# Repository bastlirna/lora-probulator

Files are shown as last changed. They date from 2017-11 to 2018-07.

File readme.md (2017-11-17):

# LoRa Probulator

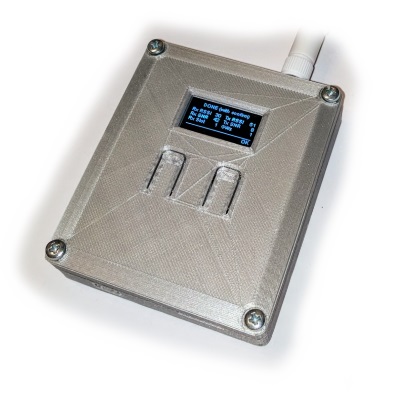
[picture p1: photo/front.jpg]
LoRa Probulator photo


*Yat Another LoRaWAN Tester*

 

<br>

## Motivation

TBD

## Key Features

- Send LoRaWAN message on button press
- Periodic sending
- Configurable message parameters (confirmation, payload, SF, etc.)
- Multiple device (ABP/OTAA, several keys configuration for testing several network providers)  

For more detail about features see [Firmware project](https://github.com/bastlirna/lora-probulator/projects/1) where are list of all ideas, selected requirements and progress of its implementation.

## Build

### Hardware

What do you need:

- [BOM](hw/bom.md)
- [PCB](https://github.com/bastlirna/lora-probulator/blob/master/hw/pcb/lora-tester-top.png)
- [3D printed enclosure ](https://github.com/bastlirna/lora-probulator/blob/master/hw/enclosure/stl/_full_preview.stl) 

For more detail see [schematics](https://github.com/bastlirna/lora-probulator/blob/master/hw/lora-tester.pdf).

### Firmware

FW is written in [Arduino libraries for ESP32](https://github.com/espressif/arduino-esp32) and build with [PlatformIO](http://platformio.org/).

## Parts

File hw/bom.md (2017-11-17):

# BOM

*What do you need:*

- Wemos LOLIN32 (ESP32 board with USB converter and battery charger)
- RFM95 (LoRa radio module)
- I2C OLED display
- 2 buttons and switch
- SMA pcb edge connector + 868 MHz antenna 
- Few resistors and capacitors
- Li-Pol battery (300 mAh)

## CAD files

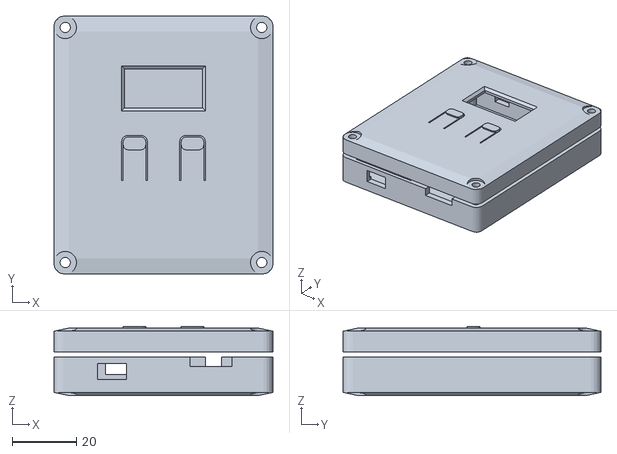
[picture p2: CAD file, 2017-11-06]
hw/enclosure/stl/_full_preview.stl
68.0 x 80.0 x 21.5

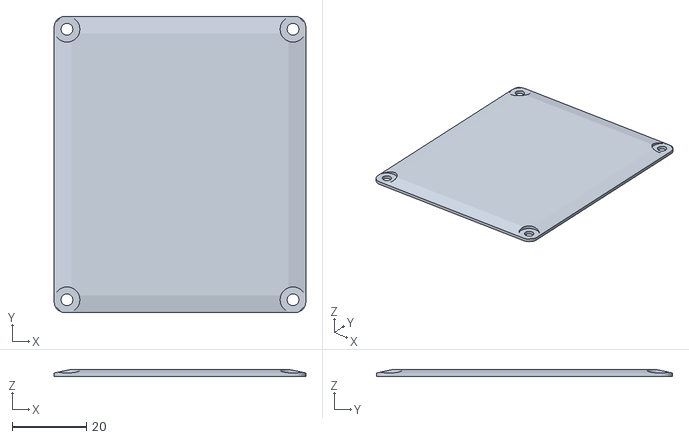
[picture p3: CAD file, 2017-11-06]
hw/enclosure/stl/btm-panel.stl
68.0 x 80.0 x 2.00

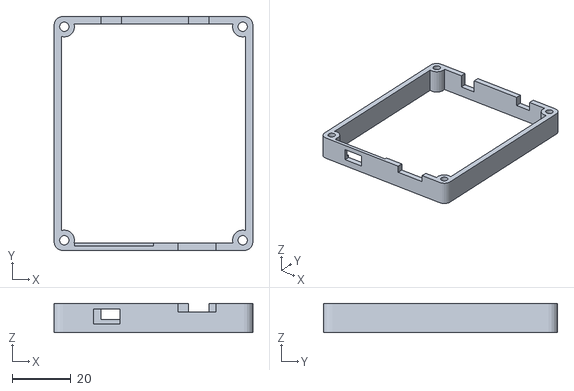
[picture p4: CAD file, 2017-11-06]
hw/enclosure/stl/btm-housing.stl
68.0 x 80.0 x 10.0

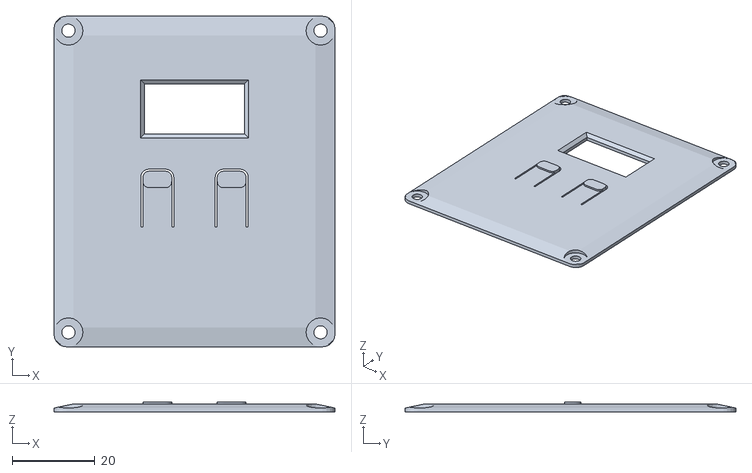
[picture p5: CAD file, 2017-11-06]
hw/enclosure/stl/top-panel.stl
68.0 x 80.0 x 2.50

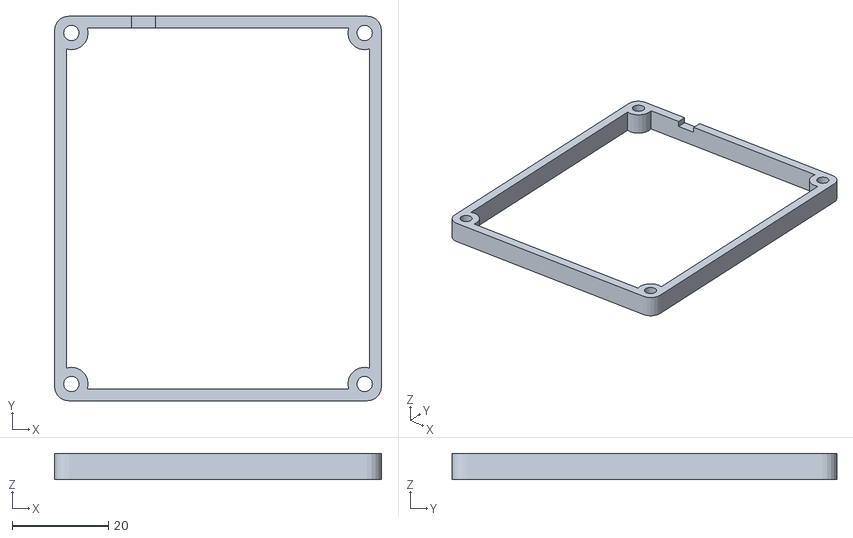
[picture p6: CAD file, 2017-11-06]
hw/enclosure/stl/top-housing.stl
68.0 x 80.0 x 5.50

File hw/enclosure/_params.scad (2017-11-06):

$fn = 20;

w = 68;
h = 80;

// tloušťka stěny
t = 2.5;

// od opačné strany než počátek
antenna_x = 18.5; 
antenna_w = 7;
antenna_h = 5;

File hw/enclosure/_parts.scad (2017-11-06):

use <_utils.scad>
include <_params.scad>

module panel() {
  
    
   difference() {
       
    union() {
      // plášť
     difference() {
        cube([w, h, 2]);
        
        union() {
          rounderer(0,0,180);  
          rounderer(w,0,-90);  
          rounderer(w,h,0);  
          rounderer(0,h,90);  
        }
        
        // ukos
        translate([0,0,1]){
          union() {
            trimmer(12, 0);
            translate([w,0,0]) trimmer(12, 90);
            translate([w,h,0]) trimmer(12, 180);
            translate([0,h,0]) trimmer(12, -90);
          }
        }
        
        // zapuštění pro šrouby
        translate([0,0,1]){
          translate([3.5,3.5,0]) cylinder(10, 3.5, 3.5, false);
          translate([w-3.5,3.5,0]) cylinder(10, 3.5, 3.5, false);
          translate([w-3.5,h-3.5,0]) cylinder(10, 3.5, 3.5, false);
          translate([3.5,h-3.5,0]) cylinder(10, 3.5, 3.5, false);
        }
      }
    }
    
    // vrtani
    translate([3.5,3.5,0]) cylinder(10, 3.2/2, 3.2/2, false);
    translate([w-3.5,3.5,0]) cylinder(10, 3.2/2, 3.2/2, false);
    translate([3.5,h-3.5,0]) cylinder(10, 3.2/2, 3.2/2, false);
    translate([w-3.5,h-3.5,0]) cylinder(10, 3.2/2, 3.2/2, false);
    
  }
  
}



module housing(d) {
  
   difference() {
       
    union() {
      // plášť
     difference() {
        cube([w, h, d]);
        
        union() {
          rounderer(0,0,180);  
          rounderer(w,0,-90);  
          rounderer(w,h,0);  
          rounderer(0,h,90);  
        }
        
        translate([t,t,0])
          cube([w-2*t, h-2*t, d]);
      }

      // domečky pro šrouby
      translate([3.5,3.5,0]) cylinder(d, 3.5, 3.5, false);
      translate([w-3.5,3.5,0]) cylinder(d, 3.5, 3.5, false);
      translate([w-3.5,h-3.5,0]) cylinder(d, 3.5, 3.5, false);
      translate([3.5,h-3.5,0]) cylinder(d, 3.5, 3.5, false);
    }
    
    // vrtani
    translate([3.5,3.5,0]) cylinder(d, 3.2/2, 3.2/2, false);
    translate([w-3.5,3.5,0]) cylinder(d, 3.2/2, 3.2/2, false);
    translate([3.5,h-3.5,0]) cylinder(d, 3.2/2, 3.2/2, false);
    translate([w-3.5,h-3.5,0]) cylinder(d, 3.2/2, 3.2/2, false);
    
  }

}

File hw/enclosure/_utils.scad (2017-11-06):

module rounderer(x, y, rot, r = 3) {
  //r = 3;
  l = 20;
  
  translate([x, y, 0]) {
    rotate([0, 0, rot]){
      translate([-r, -r, -l]) {
        difference() {
          cube([2*r, 2*r, 2*l]);
          cylinder(2*l, r, r, false);
        }
      }
    }
  }
}



module trimmer(a, rot) {
  
  l = 200;
  
  rotate([a,0, rot])
    translate([-l/2, -l/2, 0])
      cube([l, l, 10]);
  
  
}



trimmer(10, 90);

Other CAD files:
hw/enclosure/btm-housing.scad
hw/enclosure/btm-panel.scad
hw/enclosure/full.scad
hw/enclosure/top-housing.scad
hw/enclosure/top-panel.scad

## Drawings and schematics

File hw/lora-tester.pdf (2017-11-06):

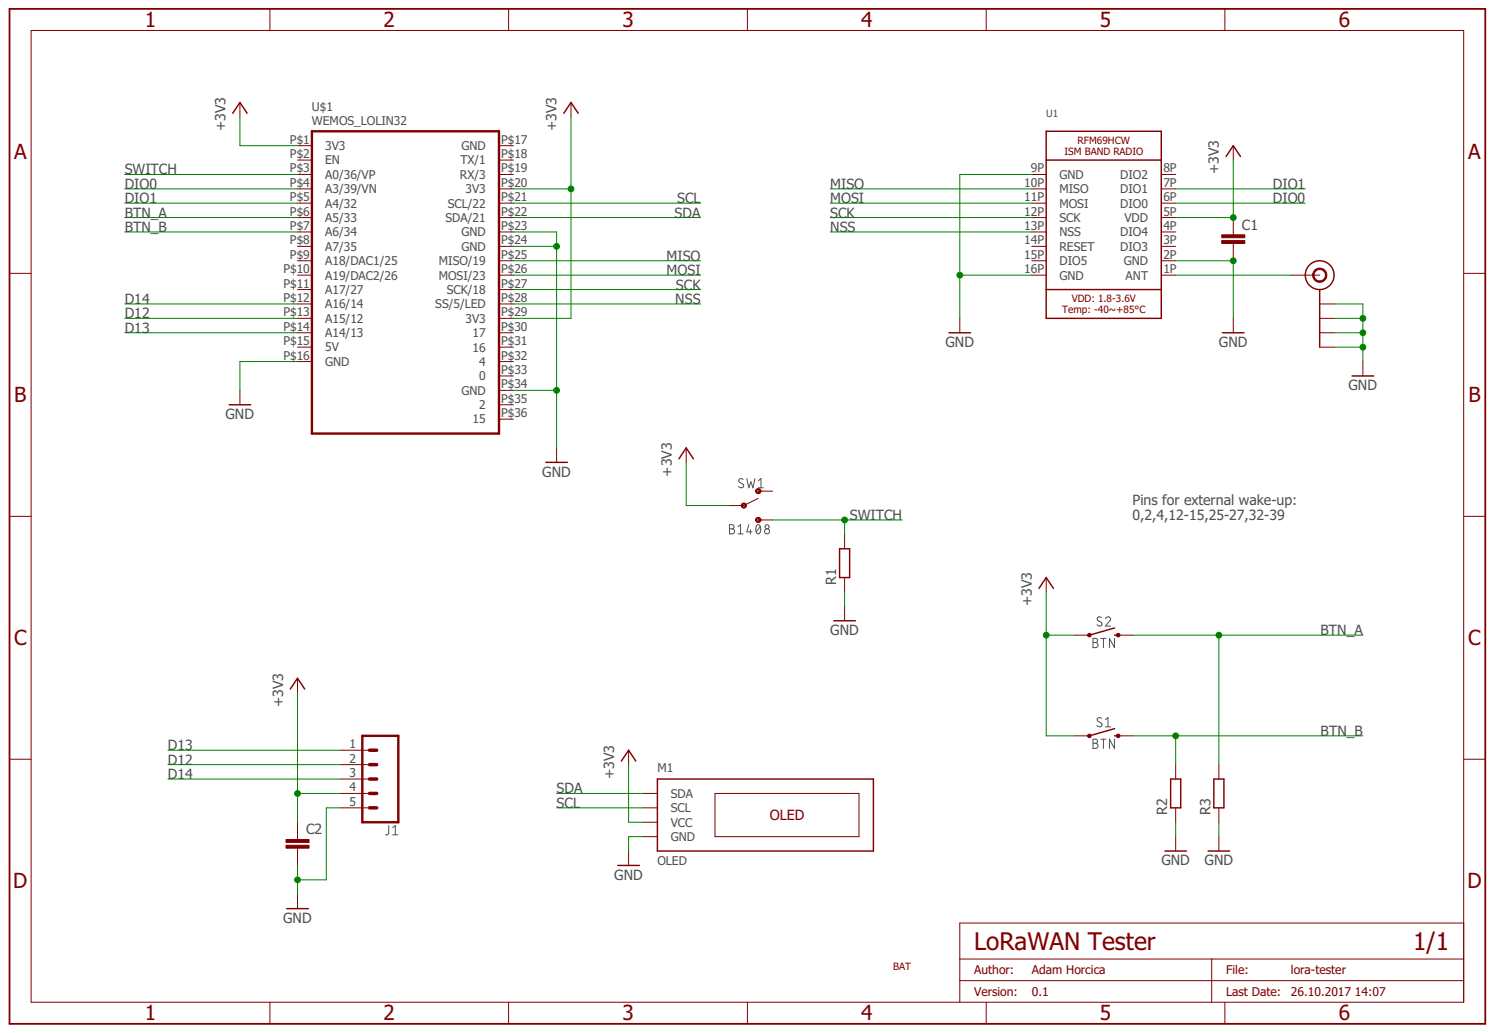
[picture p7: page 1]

Pins for external wake-up: 0,2,4,12-15,25-27,32-39

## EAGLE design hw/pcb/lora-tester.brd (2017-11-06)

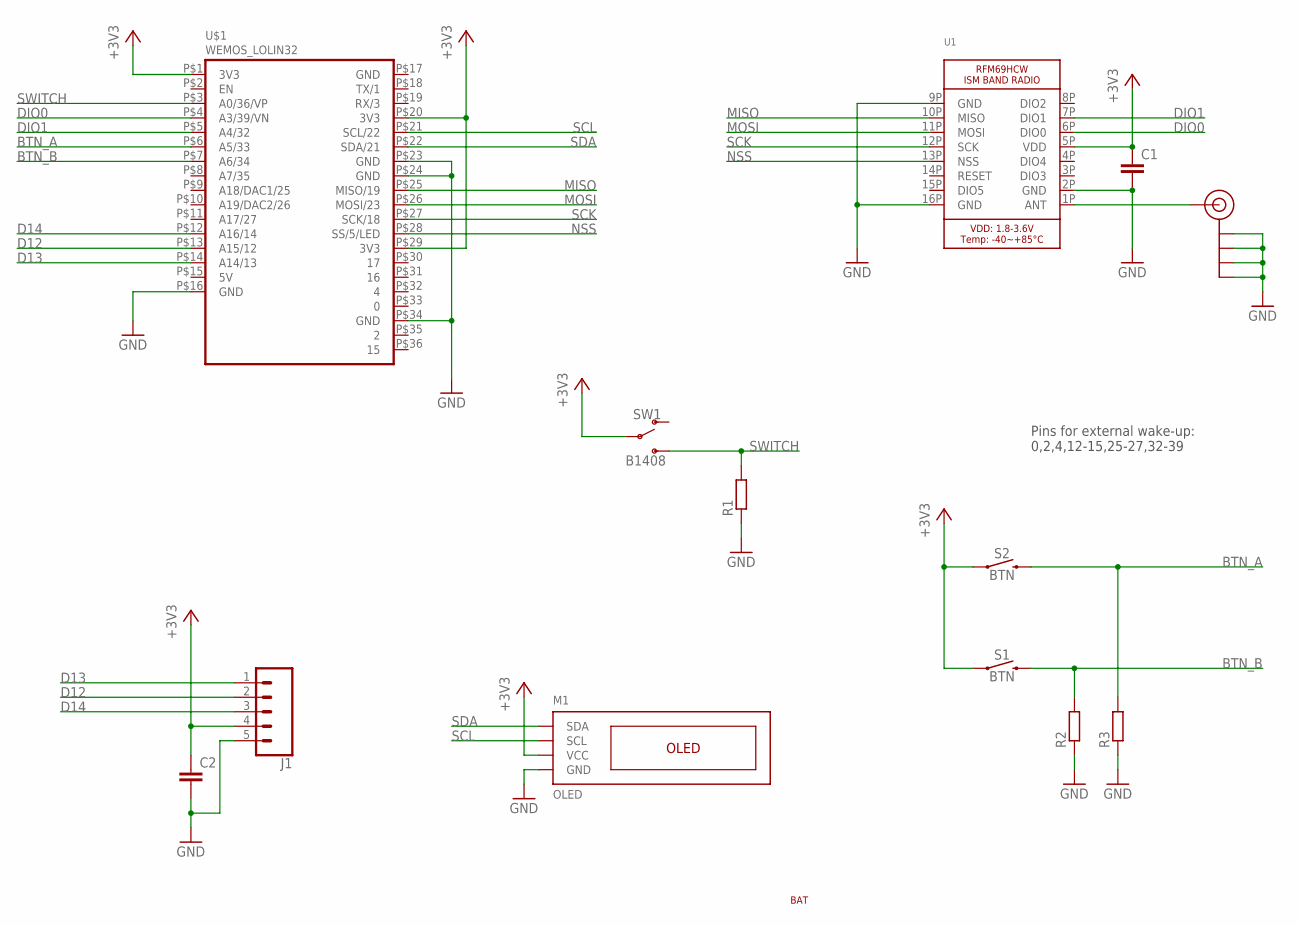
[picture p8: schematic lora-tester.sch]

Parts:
BAT: BAT
C1, C2: C-EUC1206; C1206
J1: CONN_05PTH_LONGPADS; 1X05_LONGPADS
J$2: SMA_EDGE; SMA-EDGE
M1: OLED
R1, R2, R3: R-EU_R0805; R0805
S1, S2: BTN; TACTILE_SWITCH_SMD_6.2MM_TALL
SW1: B1408; P-B1408
U1: RFM69HCW_SMT; RFMHCW_SMT
U$1: WEMOS_LOLIN32

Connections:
+3V3: C1.1, C2.1, J1.4, M1.VCC, S1.A2 (1), S2.A2 (1), SW1.P, U1.5P (VDD), U$1.P$1 (3V3), U$1.P$20 (3V3), U$1.P$29 (3V3)
BTN_A: R3.2, S2.B2 (2), U$1.P$6 (A5/33)
BTN_B: R2.2, S1.B2 (2), U$1.P$7 (A6/34)
D12: J1.2, U$1.P$13 (A15/12)
D13: J1.1, U$1.P$14 (A14/13)
D14: J1.3, U$1.P$12 (A16/14)
DIO0: U1.6P (DIO0), U$1.P$4 (A3/39/VN)
DIO1: U1.7P (DIO1), U$1.P$5 (A4/32)
GND: C1.2, C2.2, J1.5, J$2.GND@0 (GND), J$2.GND@1 (GND), J$2.GND@2 (GND), J$2.GND@3 (GND), M1.GND, R1.1, R2.1, R3.1, U1.2P (GND), U1.9P (GND), U1.16P (GND), U$1.P$16 (GND), U$1.P$23 (GND), U$1.P$24 (GND), U$1.P$34 (GND)
MISO: U1.10P (MISO), U$1.P$25 (MISO/19)
MOSI: U1.11P (MOSI), U$1.P$26 (MOSI/23)
unnamed: J$2.SIG (SIGNAL), U1.1P (ANT)
NSS: U1.13P (NSS), U$1.P$28 (SS/5/LED)
SCK: U1.12P (SCK), U$1.P$27 (SCK/18)
SCL: M1.SCL, U$1.P$21 (SCL/22)
SDA: M1.SDA, U$1.P$22 (SDA/21)
SWITCH: R1.2, SW1.S, U$1.P$3 (A0/36/VP)

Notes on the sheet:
Pins for external wake-up: 0,2,4,12-15,25-27,32-39

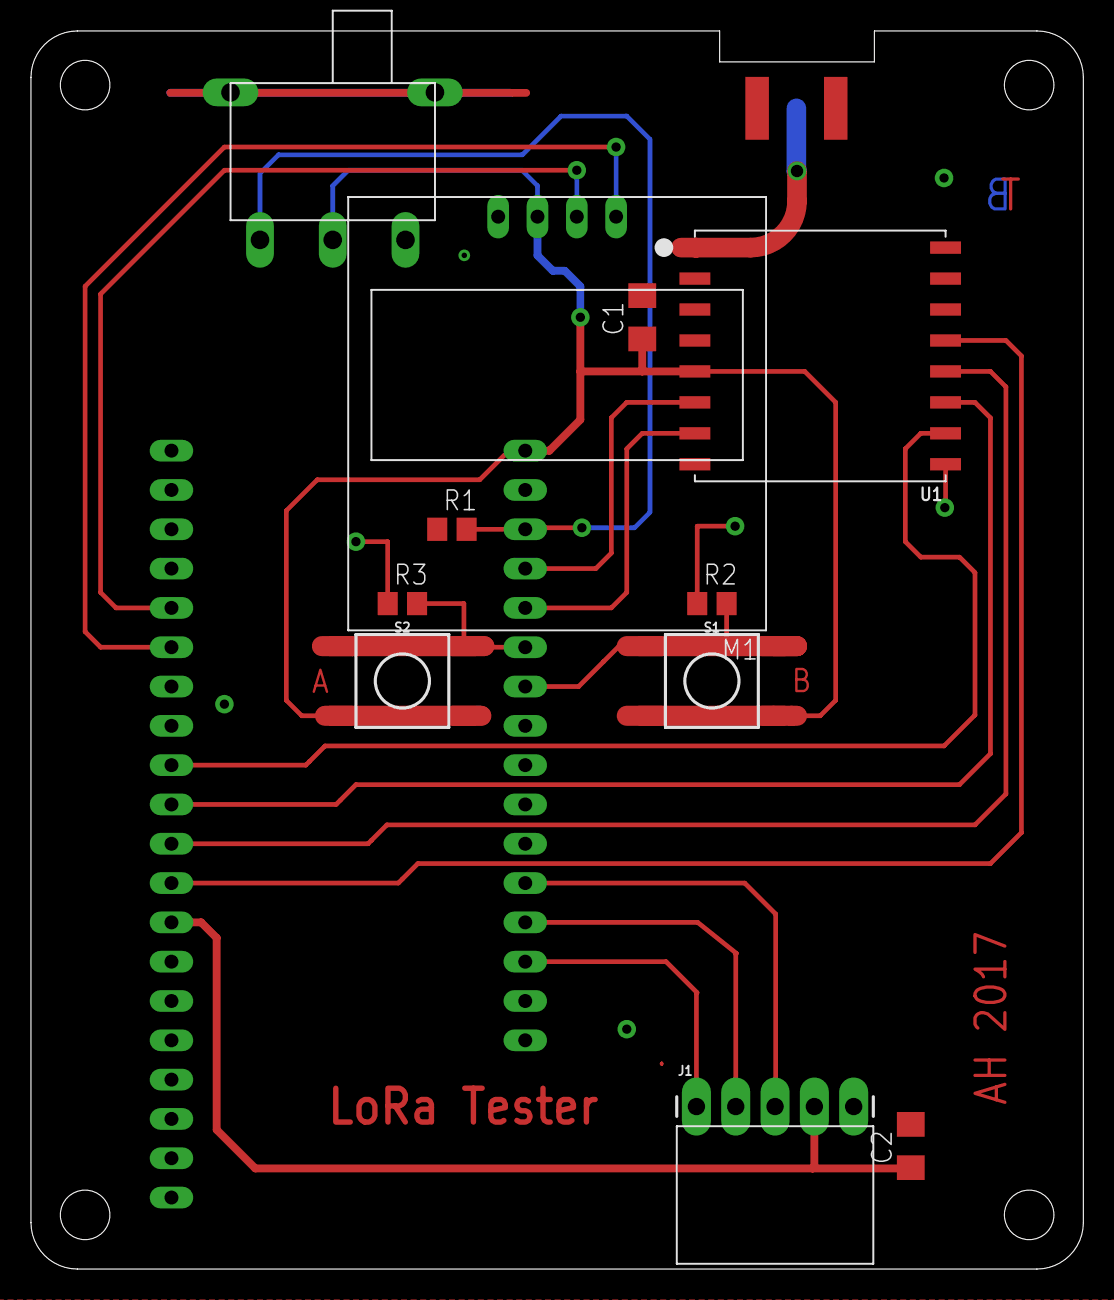
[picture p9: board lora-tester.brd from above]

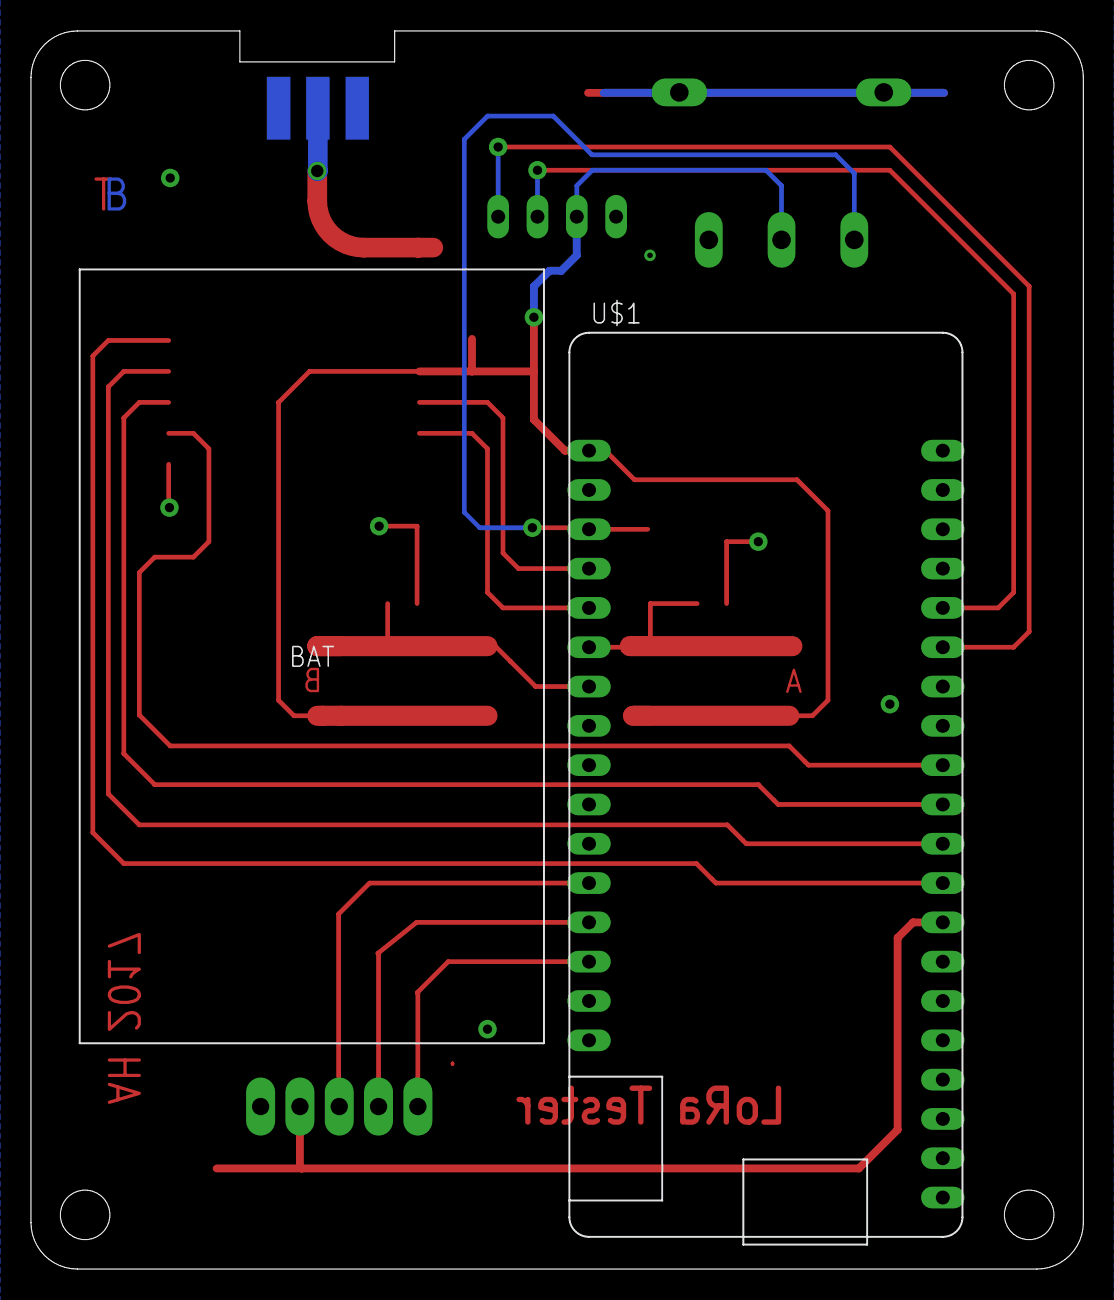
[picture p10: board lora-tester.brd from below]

Board: 2 copper layers, 68.0 x 80.0 mm, 14 parts (3 on the bottom side), 17 nets.

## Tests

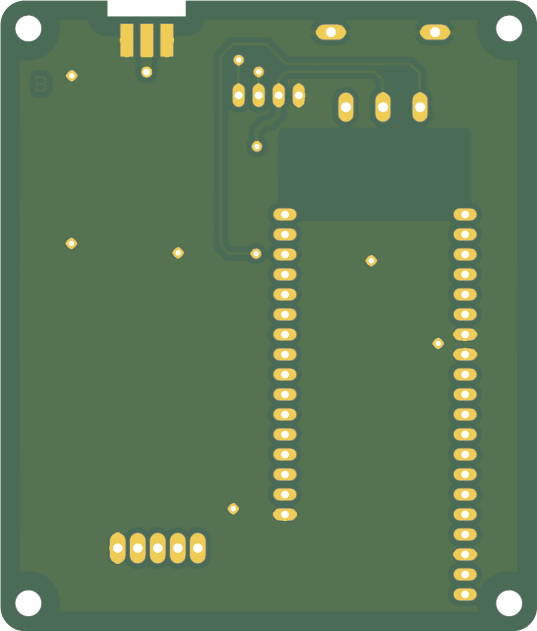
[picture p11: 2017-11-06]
hw/pcb/lora-tester-bottom.png

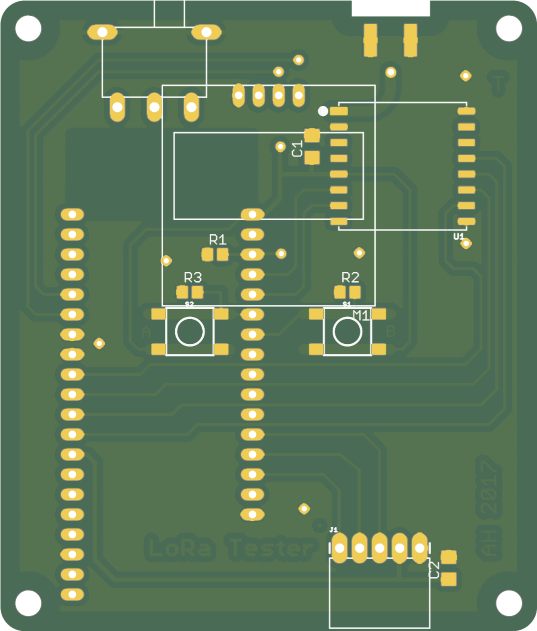
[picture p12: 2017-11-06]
hw/pcb/lora-tester-top.png

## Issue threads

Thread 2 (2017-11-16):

Power switch bug

MR-DOS, 2017-11-16:
If the power switch is turned on and off very fast, the device powers on, but doesn't turn off. The device should check for the position of power switch after setting up the power off interrupt and turn off in case it is in the OFF position.

Closed 2017-11-17.

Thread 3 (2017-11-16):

Counter reset

jhuspek, 2017-11-16:
After you switch to another device, counter should reset stats automatically.

Closed 2017-11-17.

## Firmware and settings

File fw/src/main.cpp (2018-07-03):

#include <Arduino.h>

#include <core.h>

#include <hal.h>
#include <lcd.h>
#include <lora.h>

#include <screen/home.h>
#include <screen/menu.h>
#include <screen/tx.h>
#include <screen/rx.h>

#include "Esp.h"
#include "esp_deep_sleep.h"
#include "esp_attr.h"

#define BUTTON_PIN_BITMASK 0x200000000 // 2^33 in hex

void setup() {
    Serial.begin(115200);

    delay(10);

    log_setup();
    hal_setup();
    lcd_setup();
    core_setup();
    lora_setup();

    screenMgr.change(&home);

    Log.trace("Setup done!");
}

unsigned long screenMirrorTime;

void loop() {

    hal_loop();
    lora_loop();

    runtime.loop();
    screenMgr.loop();

    if (btnOff.update() && btnOff.rose()) {

        Log.trace("Sleep request detected");

        if (runtime.periodic) {
            runtime.periodicStop();
        }

        lcd_sleep();

        delay(1500);

        if (btnOff.update() && btnOff.fell()) {
            // cancel sleep routine
            return;
        }

        Log.trace("Going to sleep");

        //esp_sleep_enable_ext0_wakeup(GPIO_NUM_33,1); //1 = High, 0 = Low
        esp_deep_sleep_enable_ext0_wakeup(GPIO_NUM_36, 0);

        display.displayOff();
        lora_off();
        esp_deep_sleep_start();

        // this will newer called
        while(1);
    }

    if (settings.screenMirror) {
        if (millis() - screenMirrorTime > 500) {
            screenMirrorTime = millis();
            display.sendBufferOnSerial();
        }
    }
}

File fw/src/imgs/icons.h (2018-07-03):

#define ack_width 9
#define ack_height 9
static char ack_bits[] PROGMEM = {
  0xFE, 0x00, 0xFF, 0x01, 0x7F, 0x01, 0xBF, 0x01, 0xDD, 0x01, 0xEB, 0x01, 
  0xF7, 0x01, 0xFF, 0x01, 0xFE, 0x00, };

#define downlink_width 9
#define downlink_height 9
static char downlink_bits[] PROGMEM = {
  0xFE, 0x00, 0xBB, 0x01, 0x1B, 0x01, 0xBB, 0x01, 0xBB, 0x01, 0xBB, 0x01, 
  0xB1, 0x01, 0xBB, 0x01, 0xFE, 0x00, };

#define uplink_width 9
#define uplink_height 9
static char uplink_bits[] PROGMEM = {
  0xFE, 0x00, 0xEF, 0x01, 0xC7, 0x01, 0xEF, 0x01, 0xEF, 0x01, 0xEF, 0x01, 
  0xEF, 0x01, 0xEF, 0x01, 0xFE, 0x00, };

#define waits_0_width 28
#define waits_0_height 7
static char waits_0_bits[] PROGMEM = {
  0x1C, 0xE0, 0x80, 0x03, 0x22, 0x10, 0x41, 0x04, 0x41, 0x08, 0x22, 0x08, 
  0x41, 0x08, 0x22, 0x08, 0x41, 0x08, 0x22, 0x08, 0x22, 0x10, 0x41, 0x04, 
  0x1C, 0xE0, 0x80, 0x03, };

#define waits_1_width 28
#define waits_1_height 7
static char waits_1_bits[] PROGMEM = {
  0x1C, 0xE0, 0x80, 0x03, 0x22, 0x10, 0x41, 0x04, 0x5D, 0x08, 0x22, 0x08, 
  0x5D, 0x08, 0x22, 0x08, 0x5D, 0x08, 0x22, 0x08, 0x22, 0x10, 0x41, 0x04, 
  0x1C, 0xE0, 0x80, 0x03, };

#define waits_2_width 28
#define waits_2_height 7
static char waits_2_bits[] PROGMEM = {
  0x1C, 0xE0, 0x80, 0x03, 0x22, 0x10, 0x41, 0x04, 0x41, 0xE8, 0x22, 0x08, 
  0x41, 0xE8, 0x22, 0x08, 0x41, 0xE8, 0x22, 0x08, 0x22, 0x10, 0x41, 0x04, 
  0x1C, 0xE0, 0x80, 0x03, };

#define waits_3_width 28
#define waits_3_height 7
static char waits_3_bits[] PROGMEM = {
  0x1C, 0xE0, 0x80, 0x03, 0x22, 0x10, 0x41, 0x04, 0x41, 0x08, 0xA2, 0x0B, 
  0x41, 0x08, 0xA2, 0x0B, 0x41, 0x08, 0xA2, 0x0B, 0x22, 0x10, 0x41, 0x04, 
  0x1C, 0xE0, 0x80, 0x03, };

#define wait_0_width 45
#define wait_0_height 9
static char wait_0_bits[] PROGMEM = {
  0x7C, 0x00, 0xF0, 0x01, 0xC0, 0x07, 0x82, 0x00, 0x08, 0x02, 0x20, 0x08, 
  0x01, 0x01, 0x04, 0x04, 0x10, 0x10, 0x01, 0x01, 0x04, 0x04, 0x10, 0x10, 
  0x01, 0x01, 0x04, 0x04, 0x10, 0x10, 0x01, 0x01, 0x04, 0x04, 0x10, 0x10, 
  0x01, 0x01, 0x04, 0x04, 0x10, 0x10, 0x82, 0x00, 0x08, 0x02, 0x20, 0x08, 
  0x7C, 0x00, 0xF0, 0x01, 0xC0, 0x07, };

#define wait_1_width 45
#define wait_1_height 9
static char wait_1_bits[] PROGMEM = {
  0x7C, 0x00, 0xF0, 0x01, 0xC0, 0x07, 0x82, 0x00, 0x08, 0x02, 0x20, 0x08, 
  0x39, 0x01, 0x04, 0x04, 0x10, 0x10, 0x7D, 0x01, 0x04, 0x04, 0x10, 0x10, 
  0x7D, 0x01, 0x04, 0x04, 0x10, 0x10, 0x7D, 0x01, 0x04, 0x04, 0x10, 0x10, 
  0x39, 0x01, 0x04, 0x04, 0x10, 0x10, 0x82, 0x00, 0x08, 0x02, 0x20, 0x08, 
  0x7C, 0x00, 0xF0, 0x01, 0xC0, 0x07, };

#define wait_2_width 45
#define wait_2_height 9
static char wait_2_bits[] PROGMEM = {
  0x7C, 0x00, 0xF0, 0x01, 0xC0, 0x07, 0x82, 0x00, 0x08, 0x02, 0x20, 0x08, 
  0x01, 0x01, 0xE4, 0x04, 0x10, 0x10, 0x01, 0x01, 0xF4, 0x05, 0x10, 0x10, 
  0x01, 0x01, 0xF4, 0x05, 0x10, 0x10, 0x01, 0x01, 0xF4, 0x05, 0x10, 0x10, 
  0x01, 0x01, 0xE4, 0x04, 0x10, 0x10, 0x82, 0x00, 0x08, 0x02, 0x20, 0x08, 
  0x7C, 0x00, 0xF0, 0x01, 0xC0, 0x07, };

#define wait_3_width 45
#define wait_3_height 9
static char wait_3_bits[] PROGMEM = {
  0x7C, 0x00, 0xF0, 0x01, 0xC0, 0x07, 0x82, 0x00, 0x08, 0x02, 0x20, 0x08, 
  0x01, 0x01, 0x04, 0x04, 0x90, 0x13, 0x01, 0x01, 0x04, 0x04, 0xD0, 0x17, 
  0x01, 0x01, 0x04, 0x04, 0xD0, 0x17, 0x01, 0x01, 0x04, 0x04, 0xD0, 0x17, 
  0x01, 0x01, 0x04, 0x04, 0x90, 0x13, 0x82, 0x00, 0x08, 0x02, 0x20, 0x08, 
  0x7C, 0x00, 0xF0, 0x01, 0xC0, 0x07, };

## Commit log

2017-11-06 Add schematics and PCB layout
    [lora-tester.brd, lora-tester.sch]
2017-11-06 Add schematics in PDF
2017-11-06 Add enclosure files for 3D printing
    [_full_pro_ilustraci.stl, _params.scad, _parts.scad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]
2017-11-06 Add dependencies for enclosure (OpenSCAD files)
2017-11-06 STL Preview
    [_full_preview.stl]
2017-11-06 Add PNG image of PCB
2017-11-17 Add bom
2017-11-17 Reset stats when device change (fix #3)
2017-11-17 Check switch state before sleep (fix #2)
    [main.cpp]
2018-06-10 Add key sample file

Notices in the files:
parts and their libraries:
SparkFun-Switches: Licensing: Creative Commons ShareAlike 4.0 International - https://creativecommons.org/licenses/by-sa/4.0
